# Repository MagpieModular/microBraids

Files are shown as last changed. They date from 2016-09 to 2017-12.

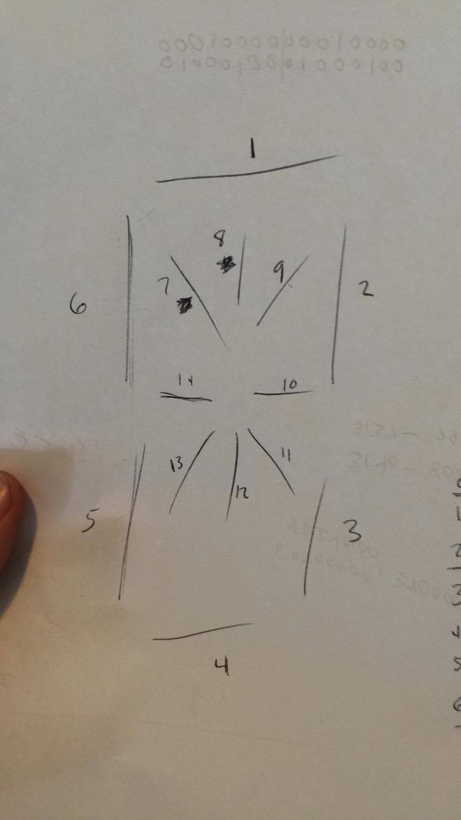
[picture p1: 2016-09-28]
Notes/14 Segment numbering.jpg

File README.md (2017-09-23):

# microBraids
μBraids in 8HP.

Braids is an amazing module. μBraids is half the space, so twice as amazing.

## Requirements
This is an advanced build. After you follow the basic build guide and solder in the 0603 & TSSOP components and you will have to flash two microprocessors with two different programmers... It is not insurmountable but if you haven't done a microprocessor based build I would recommend something simpler to start.

Nothing has been altered component-wise from v5 of Braids. Some ICs were shrunk down to TSSOP packages in order to create more space. This means that any future firmware upgrade on Braids or alternate firmware such as Tim Churches' Bees in the Trees should load and work fine.

### Hardware needed

- ISP/AVR Programmer (for the ATMEGA328P display code)
- FTDI or JTAG (ST-Linkv2) Programmer (for the main STM32 processor)
  
Note: for JTAG/ST-Linkv2, you will need a JTAG to SWD 10-pin adaptor.
The following are examples of the adaptors needed to use the mini-JTAG (SWD) connector on
the v2 board, not endorsements - [Adaptor][5], [Cable][6]

Further note: If you have a v1 board, you will only be able to use FTDI to program the
STM32 processor.

### Software needed

For flashing the main Braids firmware to this module - the microBraids firmware, using the [Mutable Instruments Vagrant Dev Environment][1] will provide the needed compilers, code and tools in a virtual machine to make the process easier. 
The μBraids can be programmed with any standard Braids firmware without modification, using the same process as the original Braids module.

For the display code - You will then need to install the [Arduino app][2] in order to program the ATMEGA328P running the display. 
The `elapsedMillis`, `Adafruit SSD 1306` and `Adafruit GFX Library` are included in this repository folder, so they do not need to be installed using the Arduino Library Manager.
Load the Ardunio sketch for the display code in the [Display Code/mbraidsv3](Display Code/mbraidsv3) folder, and use the program button in the Ardunio IDE to upload the code.
Make sure you set the board type in the Ardunio IDE `Ardunio Genuino/Uno`, and ensure the correct port and programmer type is set, based on the AVR/ISP programmer you have connected to the ISP port on microBraids.

> Note: The microBraids is designed for use with an 128x32 SPI OLED. If you manually
> install or update the libraries needed by this project, please ensure that the SSD1306
> library is correctly configured for a display size of 128x32.

## Please be advised

This board is 0603 SMT components and thus not suitable for beginners. If you would like a good introduction to the sDIY world, we recommend building a simpler through-hole kit such as the Mikrophonie and then working up in complexity from there.
There are a number of simpler SMD-based modules, and SMD practice boards can be had cheaply to practice your surface-mount soldering before attempting uBraids.

Since the layout has been altered to shrink the board down, the smaller PCB does not have all component designations marked. Instead, you can use the component overlay in the [build guide][0], or open the board layout in Diptrace to view component placements whilst building.

Before purchasing a PCB, please ensure you are comfortable with setting up the development environment needed to compile the firmware and flash these units, and understand the basic flow of working on microprocessor based builds. That said: The point of providing these boards is that learning to work SMT is not an insurmountable task and with proper research, practice and steady hands you might actually prefer it. (or not)

We are a small 2 person shop and unfortunately do not have time to be able to offer any build support or answer any questions about or troubleshoot your DIY builds.

## Want to contribute?

This is Open Source Project and could benefit from the following:

- OLED reprogramming to show the full name of the parameter and what the timbre & color adjust. There may be space for a 128x64 OLED so there is potential for this to display for more information than the regular 14 segment LEDs braids has.
- Contributions to our GitHub repositories in the form of PRs and/or filing issues if you
  find them.
- Muffwiggler project thread maintenance, feel free to chime in and support your fellow
  builders!

Please contact us if you are interested in contributing to any of the above.

  This is an at your own risk project. For the most part you can safely consider this identical to a regular braids with a few chips reduced in size and an additional atmega chip & circuit to handle the OLED display.

## Support
Support is not available through us nor Mutable Instruments nor the Mutable Instruments forums, please respect their wishes to not want to answer any questions regarding DIY builds and leave them to continue doing what they do best.

## Licence (cc-by-sa-3.0)
Original CAD file, PCB & Schematic and original design elements provided by [Mutable Instruments][3] under creative commons CC-BY-SA-3.0 license. 

This microBraids (uBraids) project is provided by [Magpie Modular][4] under Creative Commons CC-BY-SA-3.0 license.

[0]: http://github.com/MagpieModular/microBraids/blob/master/Build%20Guide/MicroBraids%20Build.pdf
[1]: http://github.com/pichenettes/mutable-dev-environment 
[2]: http://www.arduino.cc/en/Main/Software
[3]: http://mutable-instruments.net
[4]: http://magpie-modular.myshopify.com
[5]: https://www.adafruit.com/product/2094
[6]: https://www.adafruit.com/product/1675

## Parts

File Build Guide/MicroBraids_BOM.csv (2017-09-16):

Qty | Ref | Value | Mouser # | Mfr. # | Manufacturer | Description | Notes | Notes
2 | C9, C10 | 18p | 81-GRM185C1H180JA01J | GRM1885C1H180JA01J | Murata | Multilayer Ceramic Capacitors MLCC - SMD/SMT 0603 18pF 50volts C0G 5%
1 | C29 | 47p | 81-GRM185C1H470GA01J | GRM1885C1H470GA01J | Murata | Multilayer Ceramic Capacitors MLCC - SMD/SMT 0603 47pF 50volts C0G 2%
2 | C21, C22 | 100p | 81-GRM1885C1H101GA1J | GRM1885C1H101GA01J | Murata | Multilayer Ceramic Capacitors MLCC - SMD/SMT 100pF 50Volts C0G 2%
4 | C13, C14, C16, C17 | 1n | 81-GRM1885C1H102FA1J | GRM1885C1H102FA1J | Murata | Multilayer Ceramic Capacitors MLCC - SMD/SMT 0603 1000pF 50volts
17 | C1, C2, C3, C4, C5, C7, C11, C18, C20, C23, C26, C27, C28, C31, C32, C34, C35 | 100n | 963-EMK107BJ104KAHT | EMK107BJ104KAHT | Taiyo Yuden | Multilayer Ceramic Capacitors MLCC - SMD/SMT 0.1uF 16V X5R +/-10% 0603 AEC-Q200 | Added 3 jm
1 | C8 | 470n | 81-GRM18F51C474ZA01J | GRM188F51C474ZA01J | Murata | Multilayer Ceramic Capacitors MLCC - SMD/SMT 0603 0.47uF 16volts Y5V +80-20%
2 | C6, C12 | 1uF | 81-GRM18R61A105KA61J | GRM188R61A105KA61J | Murata | Multilayer Ceramic Capacitors MLCC - SMD/SMT 0603 1uF 10volts X5R 10%
1 | C24 | 10uF | 647-UWP1A100MCL | UWP1A100MCL1GB | Nichicon | Aluminum Electrolytic Capacitors - SMD 10volts 10uF 4x5.4 20%
3 | C15, C19, C33 | 22uf | 667-EEE-FK1E220R | EEE-FK1E220R | Panasonic | Aluminum Electrolytic Capacitors - SMD 22uF 25V | Added 1 jm
2 | C25, C30 | 47uF | 667-EEE-FK1V470P | EEE-FK1V470P | Panasonic | Aluminum Electrolytic Capacitors - SMD 47uF 35V
2 | R2, R49 | 4R7 | 667-ERJ-8GEYJ4R7V | ERJ-8GEYJ4R7V | Panasonic | Thick Film Resistors - SMD 1206 4.7ohms 5% Tol AEC-Q200
1 | R51 | 330R | 667-ERJ-3EKF3300V | ERJ-3EKF3300V | Panasonic | Thick Film Resistors - SMD 0603 330ohms 1% AEC-Q200
2 | R23, R55 | 1K | 667-ERJ-3EKF1001V | ERJ-3EKF1001V | Panasonic | Thick Film Resistors - SMD 0603 1Kohms 1% AEC-Q200
4 | R1, R22, R27, R33, | 10K | 667-ERJ-3EKF1002V | ERJ-3EKF1002V | Panasonic | Thick Film Resistors - SMD 0603 10Kohms 1% AEC-Q200
11 | R30, R31, R34, R35, R41, R42, R43, R44, R50, R52, R53 | 24K9 | 667-ERJ-3EKF2492V | ERJ-3EKF2492V | Panasonic | Thick Film Resistors - SMD 0603 24.9Kohms 1% AEC-Q200
2 | R45, R46 | 39K | 667-ERJ-3EKF3902V | ERJ-3EKF3902V | Panasonic | Thick Film Resistors - SMD 0603 39Kohms 1% AEC-Q200
2 | R25, R26 | 49K9 | 667-ERJ-3EKF4992V | ERJ-3EKF4992V | Panasonic | Thick Film Resistors - SMD 0603 49.9Kohms 1% AEC-Q200
6 | R24, R29, R47, R48, R54, R56 | 100K | 667-ERJ-3EKF1003V | ERJ-3EKF1003V | Panasonic | Thick Film Resistors - SMD 0603 100Kohms 1% AEC-Q200
1 | R39 | 120K | 667-ERJ-3EKF1203V | ERJ-3EKF1203V | Panasonic | Thick Film Resistors - SMD 0603 120Kohms 1% AEC-Q200
3 | R28, R32, R40 | 200K | 667-ERJ-3EKF2003V | ERJ-3EKF2003V | Panasonic | Thick Film Resistors - SMD 0603 200Kohms 1% AEC-Q200
6 | R19, R20, R21, R36, R37, R38 | 10kB | 652-PTV09A-4025UB103 | PTV09A-4025U-B103 | Bourns | Potentiometers 10K LINEAR 20% | R36, R38
1 | D3 | MB1S | 512-MB1S | MB1S |  | Bridge Rectifiers 0.5A Bridge
2 | IC1, IC2 | 74HC595 | 595-SN74HC595PWR | SN74HC595PWR | Texas Instruments | Counter Shift Registers 8-Bit Shift Register
1 | IC10 | TL072 | 595-TL072CPWR | TL072CPWR | Texas Instruments | Operational Amplifiers - Op Amps Dual Lw Nois JFET Op
1 | IC3 | LM4040C25 | 595-LM4040C25IDBZR | LM4040C25IDBZR | Texas Instruments | Voltage References 2.5-V Precision Mcrpwr Shunt .5% acc
1 | IC4 | MCP3204 | 579-MCP3204-CI/ST | MCP3204-CI/ST | Microchip | Analog to Digital Converters - ADC 12-bit SPI 4 Chl
1 | IC5 | DAC8551 | 595-DAC8551IADGKT | DAC8551IADGKT | Texas Instruments | Digital to Analog Converters - DAC 16B Ultralow Glitch Vltg Output DAC
1 | IC6 | 3.3V | 926-LM1117DT-3.3NOPB | LM1117DT-3.3/NOPB | Texas Instruments | LDO Voltage Regulators 800MA LDO LINEAR REG
1 | IC7 | MCP6004 | 579-MCP6004-I/ST | MCP6004-I/ST | Microchip | Operational Amplifiers - Op Amps Quad 1.8V 1MHz | IC7
1 | IC8 | LM4040B10 | 595-LM4040B10IDBZR | LM4040B10IDBZR | Texas Instruments | Voltage References 10-V Prec Micropower Shunt .2% accuracy
1 | IC9 | TL074 | 595-TL074CPWR | TL074CPWR | Texas Instruments | Operational Amplifiers - Op Amps Quad Low Noise JFET
4 | L1, L2, L3, L4 |  | 875-MI1210K600R-10 | MI1210K600R-10 | Laird | Ferrite Beads 60ohms 100MHz 1.5A Monolithic 1210 SMD
1 | Q5 | 8 Mhz | 815-ABLS2-8-D4Y-T | ABLS2-8.000MHZ-D4Y-T | ABRACON | Crystals 8.0MHz 30ppm 18pF -40C+85C | Q5
1 | Q6 | MMBT3904 | 863-MMBT3904LT1G | MMBT3904LT1G | ON Semiconductor | Bipolar Transistors - BJT NPN GENERAL PURPOSE
1 | U1 | AT328P | 556-ATMEGA328P-AU | ATMEGA328P-AU | Atmel | 8-bit Microcontrollers - MCU 32KB In-system Flash 20MHz 1.8V-5.5V
1 | U10 | 16 MHz | 81-CSTCE16M0V53-R0 | CSTCE16M0V53-R0 | Murata | Resonators 16MHZ .5% CHIP | U10
1 | U2 | 74HC4067 | 771-HC4067PW112 | 74HC4067PW | NXP | Multiplexer Switch ICs 16-Ch Analog, TSSOP | U2
1 | U29 | 74HC2G04GW | 771-HC2G04GW125 | 74HC2G04GW,125 | NXP | Inverters 5V 2-INPUT SINGLE | U29
1 | U3 | 5V 1A | 863-MC7805BDTRKG | MC7805BDTRKG | ON Semiconductor | Linear Voltage Regulators 5V 1A Postive
1 | UC1 | STM32F103 | 511-STM32F103CBT6 | STM32F103CBT6 | STMicroelectronics | ARM Microcontrollers - MCU 32BIT Cortex M3 128K MED Performance LN
1 | SW1 | Encoder | 858-EN11-HSM1BF20 | EN11-HSM1BF20 | TT Electronics
1 | JP1 |  | 538-87914-1026 | 87914-1026 | Molex | Headers & Wire Housings 2.54mm DRSW Hdr TH 10Ckt
1 | J8 |  | 538-87914-0616 | 87914-0616 | Molex | Headers & Wire Housings 6P HEADER
2 |  |  | 667-EVQ-Q2K01W | EVQ-Q2K01W | Panasonic | Tactile Switches Switch Light Touch 6mm Square SMD
1 |  |  | 481-0007 | 481-0007 | Eagle | Extra M7 Nut to reinforce encoder
1 |  |  | 649-221111-00010T4LF | 20021111-00010T4LF | FCI / Amphenol | Mini JTAG header

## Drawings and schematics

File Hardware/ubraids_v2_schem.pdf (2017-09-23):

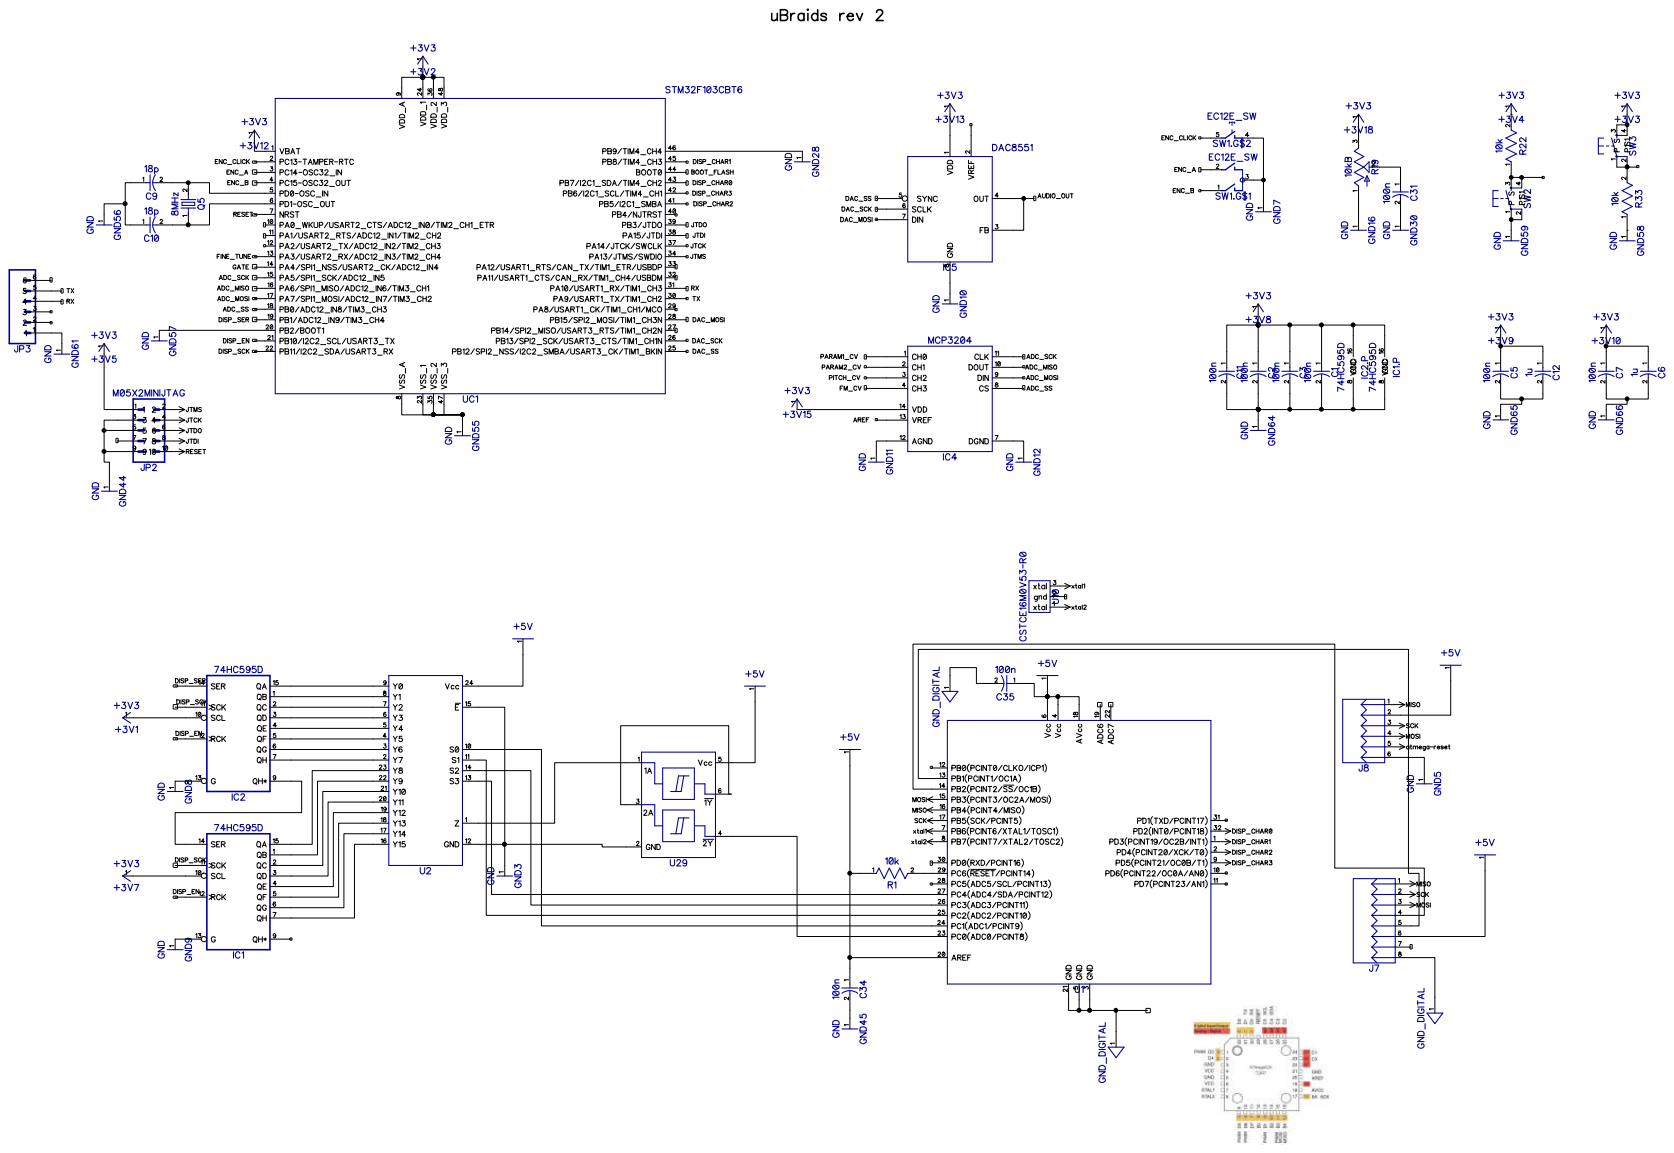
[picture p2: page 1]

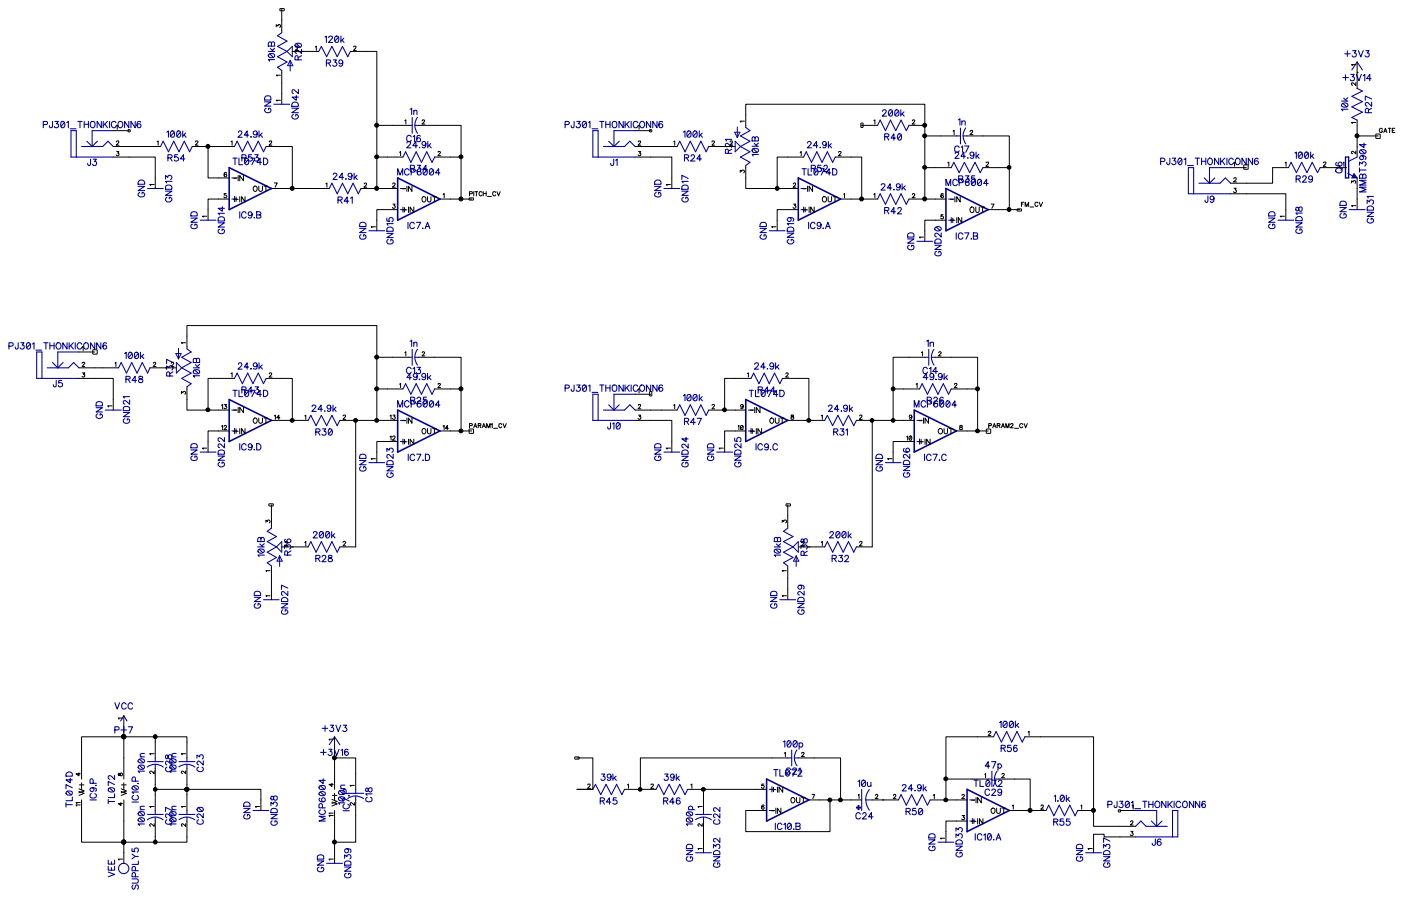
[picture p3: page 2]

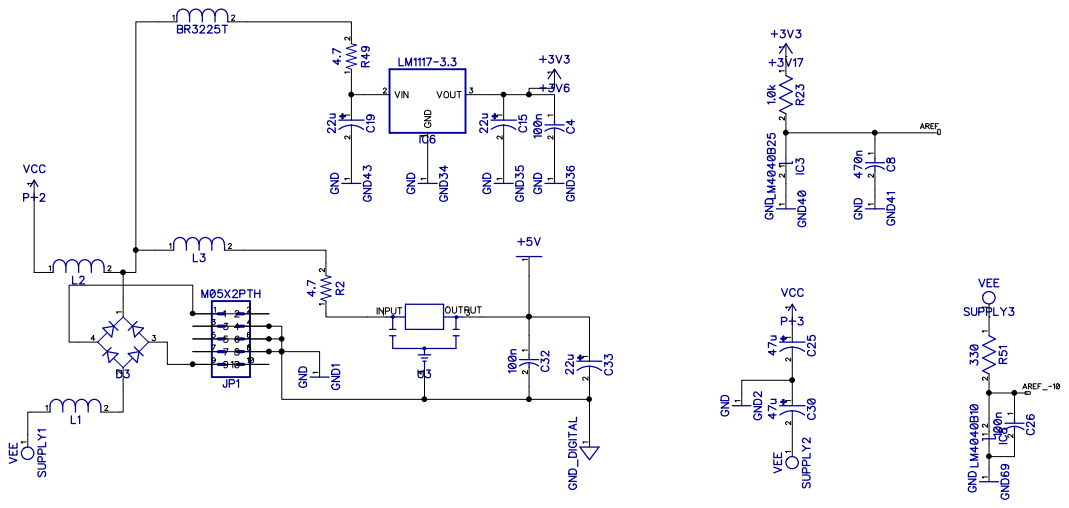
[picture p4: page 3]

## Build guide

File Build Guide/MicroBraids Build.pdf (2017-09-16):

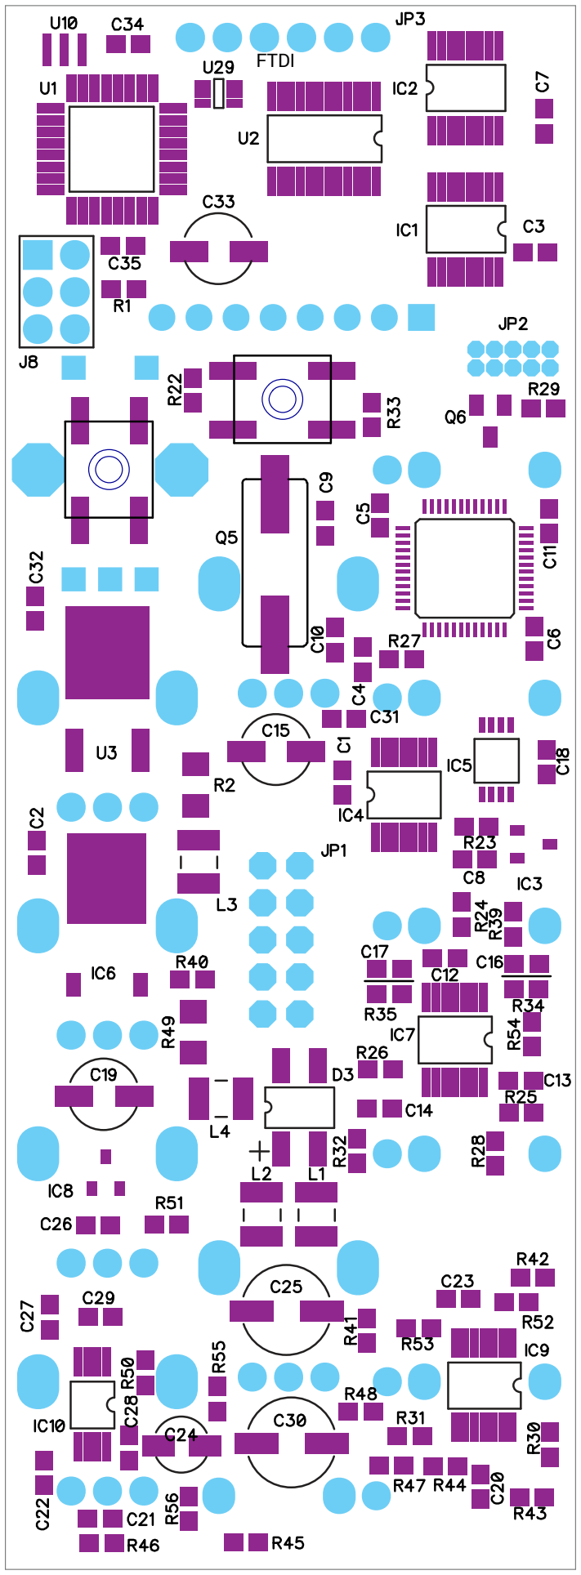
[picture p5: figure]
FTDI

Magpie - uBraids quick build guide

Place Resistors
Place SMT Capacitors
Place All IC, Electrolytics & all remaining SMT components. Note that there are two different voltages for the 4040 shunts.
Double check your work for clean joints and solder bridges.

Flashing the Main Braids Module:
Solder FTDI & Power Headers
Connect to Power, press and hold both the System and Reset Buttons releasing the reset first and then the system button. Flash via the FTDI header (I use a ftdi friend from adafruit and the Mutable Instruments Vagrant Development environment)

If the unit will not flash double check all your parts and then begin trouble shooting until you find the reason. Once the unit is flashed disconnect it from power and you can solder on the pots, jacks and oLED. I find it is easiest to use a panavise with the panel facedown

Installing the OLED
The OLED should not touch the panel, Once the OLED is installed you will need to flash the Atmega chip to convert the display information. You will need to install two libraries.

Cut file updated to add oblong mounting holes, accomodate larger encoder for DIY folks and larger pot diameter for ALPS pots.

Original CAD file and original design elements provided by Mutable Instruments under creative commons CC-BY-SA-3.0 license. mutableinstruments.com

Our design contributions are provided by Magpie Modular under Creative Commons CC-BY-SA-3.0 license.
magpiemodular.com

‘Excursion in Recursion’ fractal Vector art provided by Kris Northern under Creative Commons CC-BY-SA-3.0 license.

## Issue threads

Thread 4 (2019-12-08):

CPL files for SMT components?

stormyweathers, 2019-12-08:
I'm interested in assembling a few of these and it would be nice to use automated SMT pick-n-place for the smaller components.  This would greatly reduce the cost of manufacture.  I'd generate the files myself, but I don't see the source for the boards on here...

devec0, 2019-12-14:
The source for the boards are available as DipTrace files, the software used to design the boards, in the 'Hardware' directory.

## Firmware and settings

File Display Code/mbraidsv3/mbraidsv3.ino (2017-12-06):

#include <elapsedMillis.h>

#include <SPI.h>
#include <Wire.h>
#include <Adafruit_GFX.h>
#include <Adafruit_SSD1306.h>
int muxCount;
// If using software SPI (the default case):
#define OLED_MOSI   9
#define OLED_CLK   10
#define OLED_DC    11
#define OLED_CS    12
#define OLED_RESET 13
Adafruit_SSD1306 display(OLED_MOSI, OLED_CLK, OLED_DC, OLED_RESET, OLED_CS);
word character[4];
int histTotal;
uint16_t digit;
int readIndex[4] = {4, 5, 2, 3};
elapsedMillis sinceDisplay;
elapsedMillis sinceMux;
#if (SSD1306_LCDHEIGHT != 32)
#error("Height incorrect, please fix Adafruit_SSD1306.h!");
#endif

void setup()   {
  //char select inputs
  pinMode(2, INPUT);
  pinMode(3, INPUT);
  pinMode(4, INPUT);
  pinMode(5, INPUT);
  //
  pinMode(A0, INPUT); //mux in
  pinMode(A1, OUTPUT); //s0
  pinMode(A2, OUTPUT); //s1
  pinMode(A3, OUTPUT); //s2
  pinMode(A4, OUTPUT); //s3
  // by default, we'll generate the high voltage from the 3.3v line internally! (neat!)
  display.begin(SSD1306_SWITCHCAPVCC);
  // init done
  display.clearDisplay();
}


void loop()
{
  multiplexer();
  if (sinceDisplay > 20)
  {
    testOutput();
    //writeOutput();
    sinceDisplay = 0;
  }
}

void testOutput()
{
  display.clearDisplay();
  for (int n = 0; n < 4; n++)
  {
    digit = 32 * n;
    for (int q = 0; q < 14; q++)
    {
      if (bitRead(character[n], q))
      {
        if (q == 0)
          display.fillRoundRect(4 + digit, 1, 23, 3,1, WHITE);
        if (q == 1)
          display.fillRoundRect(27 + digit, 4, 3 , 11,1, WHITE);
        if (q == 2)
          display.fillRoundRect(27 + digit, 17, 3 , 11,1, WHITE);
        if (q == 3)
          display.fillRoundRect(4 + digit, 28, 23 , 3,1, WHITE);
        if (q == 4)
          display.fillRoundRect(2 + digit, 17, 3 , 11,1, WHITE);
        if (q == 5)
          display.fillRoundRect(2 + digit, 4, 3, 11,1, WHITE);
        if (q == 6){
          display.drawLine(5 + digit, 5, 14 + digit, 14, WHITE);
          display.drawLine(6 + digit, 5, 14 + digit, 13, WHITE);
          display.drawLine(5 + digit, 6, 13 + digit, 14, WHITE);}
        if (q == 7)
          display.fillRoundRect(15 + digit, 5, 3 , 10,1, WHITE);
        if (q == 8){
          display.drawLine(17 + digit, 14, 26 + digit, 5, WHITE);
          display.drawLine(18 + digit, 14, 26 + digit, 6, WHITE);
          display.drawLine(17 + digit, 13, 25 + digit, 5, WHITE);}
        if (q == 9)
          display.fillRoundRect(16 + digit, 15, 10 , 3,1, WHITE);
         if (q == 12){
          display.drawLine(5 + digit, 27, 14 + digit, 17, WHITE);     
          display.drawLine(5 + digit, 26, 13 + digit, 17, WHITE);   
          display.drawLine(6 + digit, 27, 14 + digit, 18, WHITE);   }
        if (q == 11)
          display.fillRoundRect(15 + digit, 17, 3 , 10,1, WHITE);
        if (q == 10){
          display.drawLine(17 + digit, 17, 27 + digit, 27, WHITE);
          display.drawLine(18 + digit, 17, 27 + digit, 26, WHITE);
          display.drawLine(17 + digit, 18, 26 + digit, 27, WHITE);}
         if (q == 13)
          display.fillRoundRect(5 + digit, 15, 9 , 3,1, WHITE);        
      }
    }
  }
  display.display();
}

void writeOutput()
{
  display.clearDisplay();
  for (int i = 0; i < 5; i++)
  {
    for (int x = 0; x < 16; x++)
    {
      if (i < 4)
      {
        if (bitRead(character[i], x))
          display.drawPixel(x * 8, i * 7, WHITE);
        else
          display.drawPixel(x * 8, i * 7, BLACK);
      }
      else
        display.drawPixel(x * 8, i * 7, WHITE);
    }
  }
  display.display();
}

void inputDetect()
{
  for (int i = 0; i < 4; i++)
  {
    if (digitalRead(readIndex[i]))
    {
      boolean inputRead;
      inputRead = digitalRead(A0);
      if (inputRead)
        bitSet(character[i], muxCount);
      else
        bitClear(character[i], muxCount);
    }
  }
}

void multiplexer()
{
  digitalWrite(A1, muxCount & 0b01);
  digitalWrite(A2, muxCount & 0b10);
  digitalWrite(A3, muxCount & 0b100);
  digitalWrite(A4, muxCount & 0b1000);
  inputDetect();
  muxCount = (muxCount + 1) % 14;
}

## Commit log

2016-09-24 Uploading Gerbers and notes
    [BoardOutline.gbr, BottomMask.gbs, TopMask.gts]
2017-03-07 Upload v2 schematic & board file.
2017-03-07 Upload v2 board masks & paste gerbers.
    [BoardOutline.gbr, BottomMask.gbr, BottomMask.gbs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]
2017-04-13 Update build guide and BOM for V2
    [MicroBraids_BOM.csv]
2017-05-24 Add all gerbers/drills needed to manufacture
    This will help those who do not have diptrace manufacture
    this project.
    [Bottom.gbr, BottomSilk.gbr, Through.drl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]
2017-09-23 Added uBraids schematic
